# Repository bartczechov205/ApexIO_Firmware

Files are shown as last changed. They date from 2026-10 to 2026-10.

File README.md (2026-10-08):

ApexIO - 23.09.2026

O projekcie

ApexIO to projekt przenośnego urządzenia do telemetrii pojazdu, pomiaru przyspieszenia i czasów okrążeń. Inspiracją były rozwiązania RaceBox i Racelogic, a celem było połączenie podobnych funkcji we własnym urządzeniu z ekranem i fizycznymi przyciskami. Projekt obejmuje oprogramowanie, własną płytkę PCB zaprojektowaną w KiCad oraz obudowę przygotowaną w Fusion 360.

Podstawą urządzenia jest ESP32-S3-WROOM. Dane o pozycji, prędkości i czasie dostarcza odbiornik GNSS NEO-F10N pracujący z częstotliwością 10 Hz, natomiast czujnik BNO085 mierzy przyspieszenie, prędkość kątową i pole magnetyczne. Wyniki są prezentowane na ekranie TFT o przekątnej 2,4 cala.

Oprogramowanie powstało w C++ z wykorzystaniem Arduino, PlatformIO i FreeRTOS. Sześć zadań rozdzielonych pomiędzy dwa rdzenie procesora odpowiada za odczyt czujników, przetwarzanie danych, obsługę przycisków i ekranu oraz zapis na kartę microSD. Zadania wymieniają dane przez kolejki, a dostęp do wspólnych zasobów jest zabezpieczony mutexami.

Do łączenia pomiarów GNSS i IMU wykorzystano bibliotekę z implementacją rozszerzonego filtra Kalmana (EKF). Dane z IMU pozwalają śledzić zmiany ruchu między odczytami GNSS, a pomiary satelitarne korygują narastające błędy oszacowania pozycji i prędkości. GeoLib przelicza współrzędne geograficzne na lokalny układ kartezjański, umożliwiając wykonywanie obliczeń odległości w metrach.

Funkcje

Live Telemetry

Tryb wyświetla aktualną prędkość, przeciążenia w osiach pojazdu, przebyty dystans, przybliżoną wysokość i kierunek ruchu. Prędkość jest wyznaczana na podstawie danych z filtra EKF i dodatkowo wygładzana filtrem medianowym. Zastosowano również ograniczenie wahań wskazania prędkości podczas postoju.

Drag Mode

Tryb mierzy czas przyspieszenia od 0 do 100 km/h oraz czas pokonania 60 stóp, 100 m, 200 m i 400 m. Wyświetla także prędkość maksymalną i aktualne przeciążenie. Po uzyskaniu gotowości pomiar rozpoczyna się automatycznie po wykryciu ruszenia, a po przejechaniu 400 m możliwy jest również pomiar drogi hamowania.

Lap Timer

Tryb mierzy czasy kolejnych okrążeń oraz pokazuje poprzedni i najlepszy wynik. Podczas okrążenia zapoznawczego tworzy wirtualne bramki, których kolejność przekraczania służy do sprawdzania poprawności kolejnych przejazdów. Funkcja live delta pokazuje bieżący zysk lub stratę czasu względem najlepszego prawidłowego okrążenia. Dane sesji są zapisywane na karcie microSD w formacie .vbo do późniejszej analizy w Circuit Tools 3.

Settings

Ustawienia pozwalają sprawdzić ustawienie urządzenia w osiach X i Y oraz wybrać przesunięcie czasu względem UTC. Można również zmieniać szerokość linii startu i mety oraz wirtualnych bramek. Dodatkowo dostępna jest regulacja zakresu paska pokazującego różnicę czasu okrążenia.

Wykorzystane biblioteki

- TFT_eSPI – obsługuje wyświetlacz TFT. Służy do rysowania ekranów, tekstu, grafik i wskaźników oraz wyświetlania wyników pomiarów.

- SparkFun u-blox GNSS v3 – odpowiada za komunikację z modułem GPS/GNSS. Umożliwia konfigurację odbiornika oraz odczyt pozycji, prędkości, czasu i liczby widocznych satelitów.

- SparkFun BNO08x Cortex Based IMU – obsługuje czujnik IMU. Dostarcza odczyty z akcelerometru, żyroskopu i magnetometru wykorzystywane do obliczania ruchu i orientacji urządzenia.

- Bolder Flight Systems Eigen – umożliwia wykonywanie obliczeń na macierzach i wektorach. W projekcie jest wykorzystywana w implementacji rozszerzonego filtra Kalmana, który łączy dane z czujników.

- SdFat – odpowiada za obsługę karty SD i plików. Umożliwia tworzenie plików z danymi przejazdu oraz zapisywanie kolejnych próbek telemetrii.

- Adafruit INA219 – obsługuje układ pomiaru napięcia i prądu. W projekcie służy do odczytu napięcia wykorzystywanego przez wskaźnik baterii.

- GeoLib - zawiera obliczenia związane ze współrzędnymi geograficznymi. Ułatwia przeliczanie pozycji na lokalny układ współrzędnych wykorzystywany w pomiarach przejazdu. 

- Adafruit BusIO – zapewnia funkcje komunikacji przez magistrale I²C i SPI. Jest biblioteką pomocniczą wykorzystywaną przez sterowniki Adafruit, między innymi INA219.

- Adafruit GFX Library – zawiera podstawowe funkcje rysowania tekstu i kształtów. Jest dołączona w zestawie bibliotek Adafruit; za interfejs wyświetlacza w ApexIO odpowiada TFT_eSPI.

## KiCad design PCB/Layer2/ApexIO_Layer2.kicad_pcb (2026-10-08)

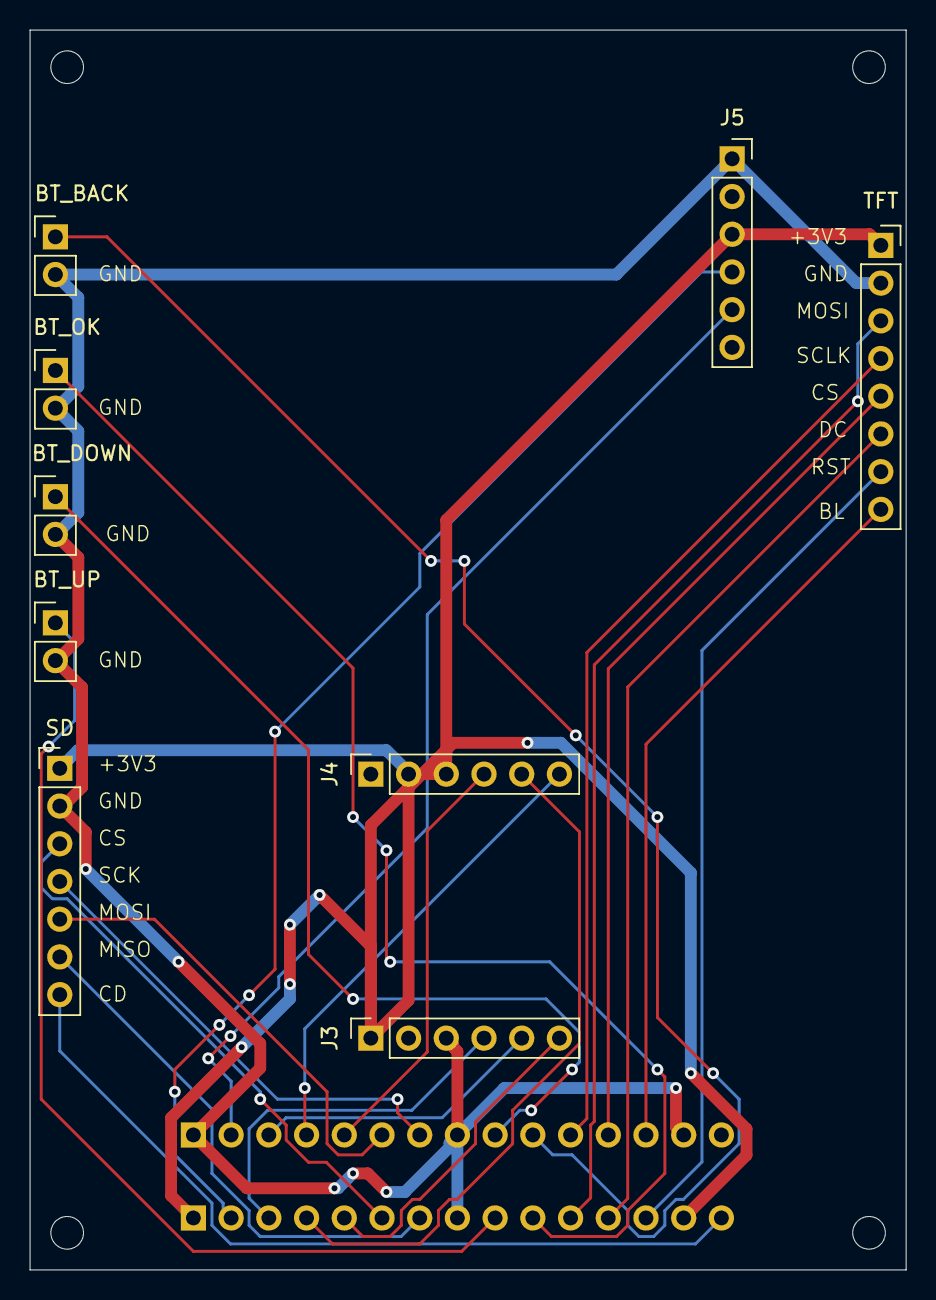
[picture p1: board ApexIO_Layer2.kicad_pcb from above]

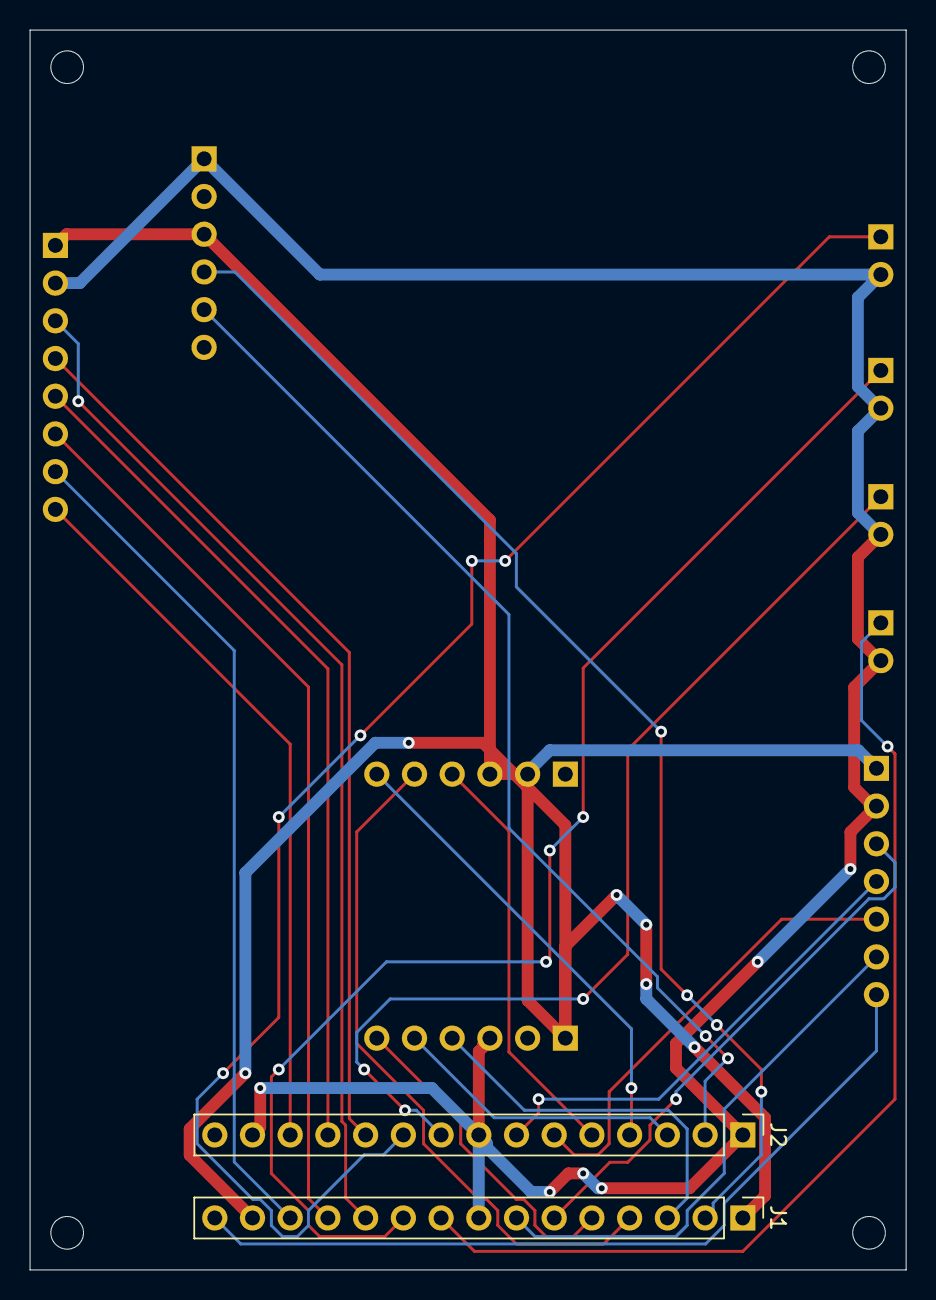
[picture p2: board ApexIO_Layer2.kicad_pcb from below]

Board: 2 copper layers, 59.0 x 83.5 mm, 11 parts (2 on the bottom side), 25 nets.

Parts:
BT_BACK: BUTTON_BACK; PinHeader_1x02_P2.54mm_Vertical
BT_DOWN: BUTTON_OK; PinHeader_1x02_P2.54mm_Vertical
BT_OK: BUTTON_DOWN; PinHeader_1x02_P2.54mm_Vertical
BT_UP: BUTTON_UP; PinHeader_1x02_P2.54mm_Vertical
J1: STACK_A; PinHeader_1x15_P2.54mm_Vertical
J2: STACK_B; PinHeader_1x15_P2.54mm_Vertical
J3: IMU_R1; PinSocket_1x06_P2.54mm_Vertical
J4: IMU_R2; PinSocket_1x06_P2.54mm_Vertical
J5: GPS_GNSS; PinSocket_1x06_P2.54mm_Vertical
SD: SD_WIRES; PinHeader_1x07_P2.54mm_Vertical
TFT: STACK_3; PinSocket_1x08_P2.54mm_Vertical

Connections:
/+3V3: J1.1, J1.14, J3.1, J4.2, J4.3, J5.3, SD.1, TFT.1
/BTN_BACK: BT_BACK.1, J2.10
/BTN_DOWN: BT_OK.1, J2.9
/BTN_OK: BT_DOWN.1, J1.10
/BTN_UP: BT_UP.1, J1.9
/GND: BT_BACK.2, BT_DOWN.2, BT_OK.2, BT_UP.2, J1.8, J2.1, J2.8, J2.14, J3.3, J5.1, SD.2, TFT.2
/GPS_RX: J2.2, J5.5
/GPS_TX: J1.2, J5.4
/IMU_CS: J2.4, J4.6
/IMU_INT: J1.5, J3.6
/IMU_MISO: J2.3, J3.5
/IMU_MOSI: J1.4, J4.5
/IMU_RST: J2.5, J4.4
/IMU_SCK: J1.3, J3.4
/SD_CD: J1.15, SD.7
/SD_CS: J1.6, SD.3
/SD_MISO: J1.7, SD.6
/SD_MOSI: J2.6, SD.5
/SD_SCK: J2.7, SD.4
/TFT_BL_CTRL: J2.13, TFT.8
/TFT_CS: J2.12, TFT.5
/TFT_DC: J1.12, TFT.6
/TFT_MOSI: J1.11, TFT.3
/TFT_RST: J1.13, TFT.7
/TFT_SCLK: J2.11, TFT.4

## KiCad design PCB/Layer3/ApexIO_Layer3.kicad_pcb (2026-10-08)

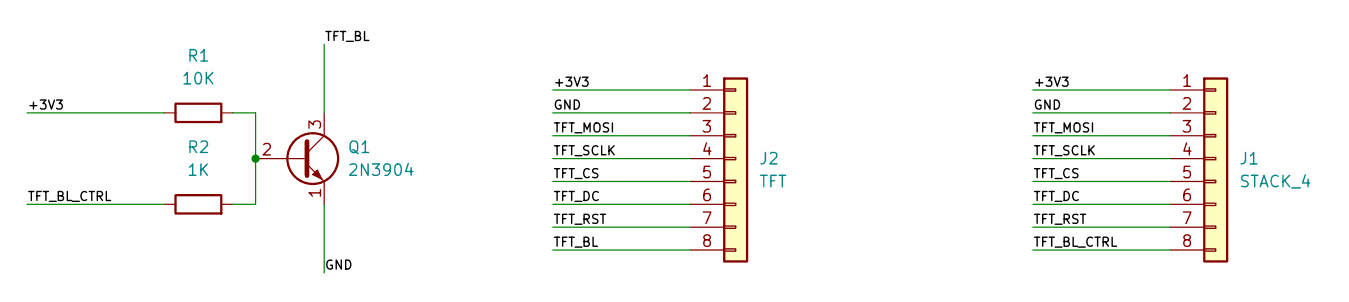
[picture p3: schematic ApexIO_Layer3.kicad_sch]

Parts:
J1: STACK_4; PinHeader_1x08_P2.54mm_Vertical
J2: TFT; PinHeader_1x08_P2.54mm_Vertical
Q1: 2N3904; TO-92_Inline
R1: 10K; R_Axial_DIN0207_L6.3mm_D2.5mm_P7.62mm_Horizontal
R2: 1K; R_Axial_DIN0207_L6.3mm_D2.5mm_P7.62mm_Horizontal

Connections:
/+3V3: J1.1, J2.1, R1.1
/GND: J1.2, J2.2, Q1.1 (E)
/TFT_BL: J2.8, Q1.3 (C)
/TFT_BL_CTRL: J1.8, R2.1
/TFT_CS: J1.5, J2.5
/TFT_DC: J1.6, J2.6
/TFT_MOSI: J1.3, J2.3
/TFT_RST: J1.7, J2.7
/TFT_SCLK: J1.4, J2.4
unnamed: Q1.2 (B), R1.2, R2.2

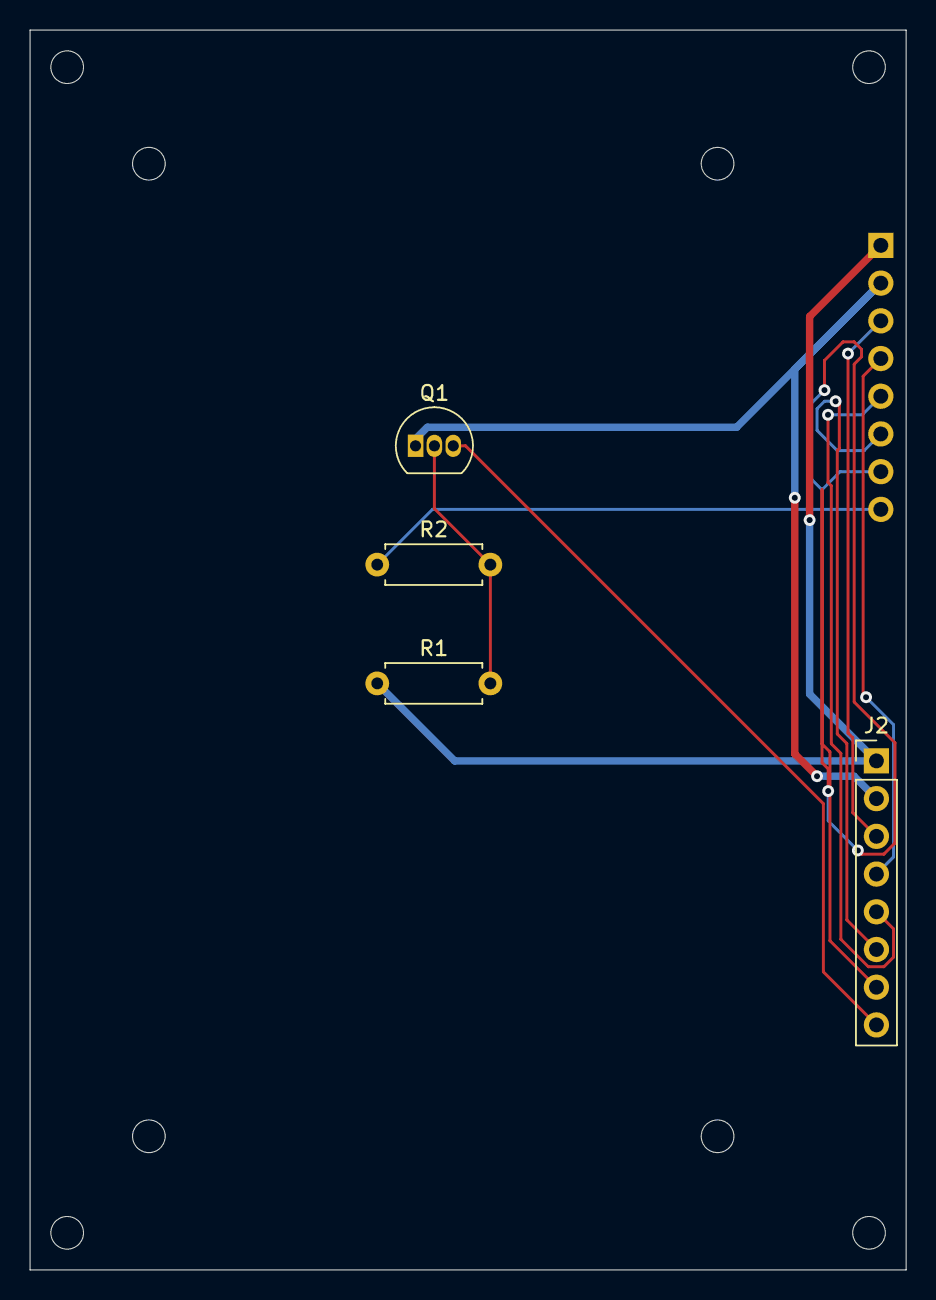
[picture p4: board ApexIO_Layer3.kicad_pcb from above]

Board: 2 copper layers, 59.0 x 83.5 mm, 5 parts (1 on the bottom side), 10 nets.

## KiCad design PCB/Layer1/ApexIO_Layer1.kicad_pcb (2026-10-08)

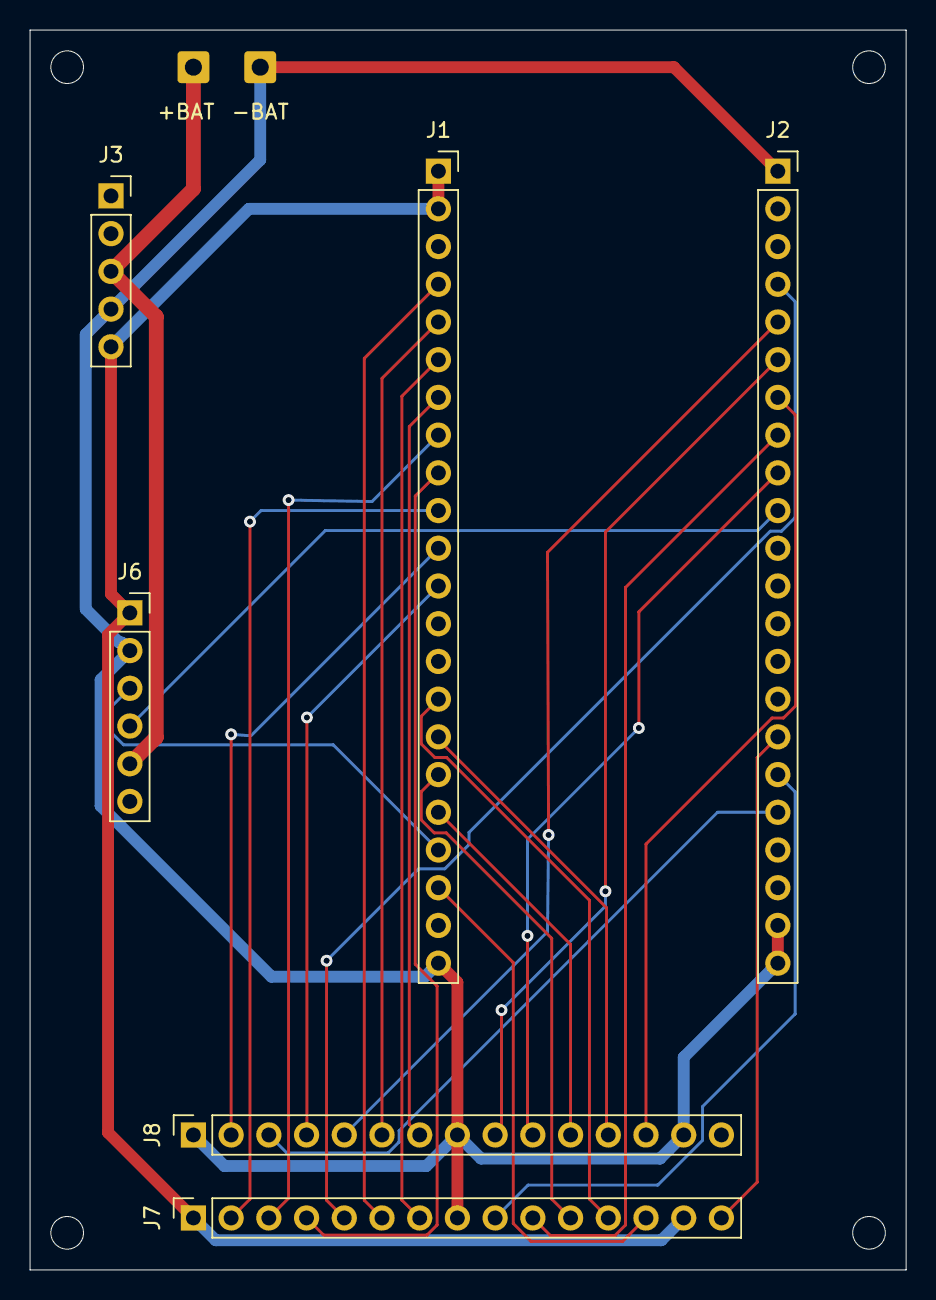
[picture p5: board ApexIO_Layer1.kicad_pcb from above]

Board: 2 copper layers, 59.0 x 83.5 mm, 8 parts (0 on the bottom side), 28 nets.

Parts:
+BAT: BAT_PLUS; SolderWire-0.5sqmm_1x01_D0.9mm_OD2.1mm
-BAT: BAT_MINUS; SolderWire-0.5sqmm_1x01_D0.9mm_OD2.1mm
J1: ESP32_P1; PinSocket_1x22_P2.54mm_Vertical
J2: ESP32_P2; PinSocket_1x22_P2.54mm_Vertical
J3: Pololu D24V22F3; PinSocket_1x05_P2.54mm_Vertical
J6: INA219_Adafruit; PinSocket_1x06_P2.54mm_Vertical
J7: STACK_A; PinSocket_1x15_P2.54mm_Vertical
J8: STACK_B; PinSocket_1x15_P2.54mm_Vertical

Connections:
/+3V3: J1.1, J1.2, J3.5, J6.1, J7.1, J7.14
/BTN_BACK: J2.9, J8.10
/BTN_DOWN: J2.6, J8.9
/BTN_OK: J2.8, J7.10
/BTN_UP: J2.17, J7.9
/GND: -BAT.1 (Pin_1_1), J1.22, J2.1, J2.21, J2.22, J3.4, J6.2, J7.8, J8.1, J8.8, J8.14
/GPS_RX: J1.11, J8.2
/GPS_TX: J1.10, J7.2
/I2C_SCL: J1.19, J6.3
/I2C_SDA: J2.10, J6.4
/IMU_CS: J1.12, J8.4
/IMU_INT: J2.4, J7.5
/IMU_MISO: J2.18, J8.3
/IMU_MOSI: J1.9, J7.4
/IMU_RST: J2.5, J8.5
/IMU_SCK: J1.8, J7.3
/SD_CD: J2.16, J7.15
/SD_CS: J1.4, J7.6
/SD_MISO: J1.6, J7.7
/SD_MOSI: J1.5, J8.6
/SD_SCK: J1.7, J8.7
/TFT_BL_CTRL: J2.7, J8.13
/TFT_CS: J1.16, J8.12
/TFT_DC: J1.15, J7.12
/TFT_MOSI: J1.17, J7.11
/TFT_RST: J1.20, J7.13
/TFT_SCLK: J1.18, J8.11
/VBAT: +BAT.1 (Pin_1_1), J3.3, J6.5

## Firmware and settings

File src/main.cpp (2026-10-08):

#include <Arduino.h>
#include "Macro.h"
#include "SharedBegin.h"
#include "ekfNavINS.h"
#include <TFT_eSPI.h>
#include "AppStateManager.h"
#include "TelemetryEngine.h"
#include "TFTManager.h"
#include "SystemDataUpdater.h"
#include "AppResources.h"
#include "SDManager.h"

SharedBegin sharedBegin;
IMUManager imuManager;
GPSManager gpsManager;
ekfNavINS ekfNavIns;
AppStateManager appStateManager;
TelemetryEngine telemetryEngine;
TFTManager tftManager;
SDManager sdManager;

SystemDataUpdater systemDataUpdater;
AppResources resources;

void IRAM_ATTR imuInt()
{
    BaseType_t xHigherPriorityTaskWoken = pdFALSE;

    xSemaphoreGiveFromISR(resources.imuSemaphore, &xHigherPriorityTaskWoken);

    portYIELD_FROM_ISR(xHigherPriorityTaskWoken);
}

void vTaskIMU(void *pvParameters)
{
    for (;;)
    {
        imuManager.processImuData(resources,ekfNavIns,systemDataUpdater);
        vTaskDelay(pdMS_TO_TICKS(1));
    }
}

void vTaskGPS(void *pvParameters)
{
    for (;;)
    {
        gpsManager.processGpsData(resources, ekfNavIns);

        vTaskDelay(pdMS_TO_TICKS(5));
    }
}

void vTaskAppState(void *pvParametrs)
{
    bool validFix = false;
    bool canContinue = false;

    for (;;)
    {
        if (xSemaphoreTake(resources.systemStateMutex, portMAX_DELAY) == pdTRUE)
        {
            validFix = resources.validFix;

            if (resources.validFix && resources.systemReady)
            {
                canContinue = true;
            }
            else
            {
                canContinue = false;
            }
            xSemaphoreGive(resources.systemStateMutex);
        }

        appStateManager.updateState(validFix, canContinue);
        vTaskDelay(pdMS_TO_TICKS(5));
    }
}

void vTaskTelemetryEngine(void *pvParameters)
{
    for (;;)
    {
        if (xSemaphoreTake(resources.systemStateMutex, portMAX_DELAY) == pdTRUE)
        {
            telemetryEngine.updateTelemetryEngine(resources.systemData);
            xSemaphoreGive(resources.systemStateMutex);
        }

        telemetryEngine.processDataForState(appStateManager);

        vTaskDelay(pdMS_TO_TICKS(10));
    }
}

void vTaskTFT(void *pvParametrs)
{
    DisplayResources displayResources;

    tftManager.drawSplashScreen();

    displayResources.startTime = millis();

    for (;;)
    {
        tftManager.updateDisplay(resources,appStateManager,displayResources);

        vTaskDelay(pdMS_TO_TICKS(5));
    }
}

void vTaskSD(void *pvParameters)
{
    SDData sdReceived;

    bool isFileOpen = false;

    if (!sdManager.begin())
    {
        vTaskDelete(NULL);
    }

    for (;;)
    {
        if (xQueueReceive(resources.lapTimerSDQueue, &sdReceived, portMAX_DELAY) == pdTRUE)
        {
            sdManager.processSdRecord(sdReceived, isFileOpen);
        }
    }
}

void setup()
{
    digitalWrite(TFT_BL, HIGH);
    pinMode(TFT_BL, OUTPUT);

    pinMode(SD_DETECT_PIN, INPUT_PULLUP);

    Serial.begin(115200);
    delay(200);

    resources.imuSemaphore = xSemaphoreCreateBinary();
    resources.systemStateMutex = xSemaphoreCreateMutex();
    resources.serialMonitorMutex = xSemaphoreCreateMutex();

    resources.imuQueue = xQueueCreate(10, sizeof(imuData));
    resources.magQueue = xQueueCreate(10, sizeof(magData));
    resources.gpsPositionQueue = xQueueCreate(10, sizeof(gpsPosData));
    resources.gpsVelocityQueue = xQueueCreate(10, sizeof(gpsVelData));
    resources.gpsExtraQueue = xQueueCreate(10, sizeof(gpsExtraData));
    resources.lapTimerSDQueue = xQueueCreate(128, sizeof(SDData));

    resources.axisCalibQueue = xQueueCreate(1, sizeof(AxisCalibData));
    resources.liveTelemetryQueue = xQueueCreate(1, sizeof(LiveTeleData));
    resources.dragModeQueue = xQueueCreate(1, sizeof(DragModeData));
    resources.lapTimerQueue = xQueueCreate(1, sizeof(LapTimerData));

    if (!sharedBegin.begin(resources))
    {
        return;
    }

    attachInterrupt(digitalPinToInterrupt(IMU_INT), imuInt, FALLING);

    xTaskCreatePinnedToCore(vTaskIMU, "vTaskIMU", 16384, NULL, 5, NULL, 0);
    xTaskCreatePinnedToCore(vTaskGPS, "vTaskGPS", 16384, NULL, 4, NULL, 0);
    xTaskCreatePinnedToCore(vTaskAppState, "vTaskAppState", 4096, NULL, 2, NULL, 1);
    xTaskCreatePinnedToCore(vTaskTFT, "vTaskTFT", 8192, NULL, 2, NULL, 1);
    xTaskCreatePinnedToCore(vTaskTelemetryEngine, "vTaskTelemetryEngine", 8192, NULL, 3, NULL, 1);
    xTaskCreatePinnedToCore(vTaskSD, "vTaskSD", 8192, NULL, 1, NULL, 1);

    delay(500);
}

void loop() {}

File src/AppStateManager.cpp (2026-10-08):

#include "AppStateManager.h"
#include "AppResources.h"

extern AppResources resources;

void AppStateManager::begin()
{
    currentState = State_Splash;
    okPressed = false;
    wasPressed = false;

    Serial.println("Splash screen, press OK");
}

void AppStateManager::updateState(bool validFix, bool canContinue)
{
    bool upState = digitalRead(btn_up.pin);
    bool downState = digitalRead(btn_down.pin);
    bool okState = digitalRead(btn_ok.pin);
    bool backState = digitalRead(btn_back.pin);

    bool upClick = false;
    bool downClick = false;
    bool okClick = false;
    bool backClick = false;

    if (upState == LOW && btn_up.lastPinState == HIGH)
    {
        if (millis() - btn_up.lastButtonPressTime > debounceDelay)
        {
            upClick = true;
            btn_up.lastButtonPressTime = millis();
        }
    }

    if (downState == LOW && btn_down.lastPinState == HIGH)
    {
        if (millis() - btn_down.lastButtonPressTime > debounceDelay)
        {
            downClick = true;
            btn_down.lastButtonPressTime = millis();
        }
    }

    if (okState == LOW && btn_ok.lastPinState == HIGH)
    {
        if (millis() - btn_ok.lastButtonPressTime > debounceDelay)
        {
            okClick = true;
            btn_ok.lastButtonPressTime = millis();
        }
    }

    if (backState == LOW && btn_back.lastPinState == HIGH)
    {
        if (millis() - btn_back.lastButtonPressTime > debounceDelay)
        {
            backClick = true;
            btn_back.lastButtonPressTime = millis();
        }
    }

    switch (currentState)
    {
    case State_Splash:
        if (validFix && canContinue && okClick)
        {
            currentState = State_LiveTeleSel;
        }
        break;

    case State_LiveTeleSel:
        if (okClick)
        {
            currentState = State_LiveTele;
        }
        else if (downClick)
        {
            currentState = State_DragModeSel;
        }
        else if (upClick)
        {
            currentState = State_SettingsSel;
        }
        break;

    case State_DragModeSel:
        if (okClick)
        {
            currentState = State_DragMode;
        }
        else if (downClick)
        {
            currentState = State_LapTimerSel;
        }
        else if (upClick)
        {
            currentState = State_LiveTeleSel;
        }
        break;

    case State_LapTimerSel:
        if (okClick)
        {
            currentState = State_LapTimer;
        }
        else if (downClick)
        {
            currentState = State_SettingsSel;
        }
        else if (upClick)
        {
            currentState = State_DragModeSel;
        }
        break;

    case State_SettingsSel:
        if (okClick)
        {
            currentState = State_Settings_Axis_CalibSel;
        }
        else if (downClick)
        {
            currentState = State_LiveTeleSel;
        }
        else if (upClick)
        {
            currentState = State_LapTimerSel;
        }
        break;

    case State_LiveTele:
        if (backClick)
        {
            currentState = State_LiveTeleSel;
        }
        break;

    case State_DragMode:
        if (backClick)
        {
            currentState = State_DragModeSel;
        }
        else if (okClick)
        {
            okPressed = true;
        }
        break;

    case State_LapTimer:
        if (backClick)
        {
            currentState = State_LapTimerSel;
        }
        else if (okClick)
        {
            okPressed = true;
        }
        break;

    case State_Settings_Axis_CalibSel:
        if (backClick)
        {
            currentState = State_SettingsSel;
        }
        else if (okClick)
        {
            currentState = State_Settings_Axis_Calib;
        }
        else if (downClick)
        {
            currentState = State_Settings_UTC_OFFSETSel;
        }
        else if (upClick)
        {
            currentState = State_Settings_ABOUTSel;
        }
        break;

    case State_Settings_UTC_OFFSETSel:
        if (backClick)
        {
            currentState = State_SettingsSel;
        }
        else if (okClick)
        {
            currentState = State_Settings_UTC_OFFSET;
        }
        else if (downClick)
        {
            currentState = State_Settings_GATE_SETUPSel;
        }
        else if (upClick)
        {
            currentState = State_Settings_Axis_CalibSel;
        }
        break;

    case State_Settings_GATE_SETUPSel:
        if (backClick)
        {
            currentState = State_SettingsSel;
        }
        else if (okClick)
        {
            currentState = State_StartLineWidthSel;
        }
        else if (downClick)
        {
            currentState = State_Settings_ABOUTSel;
        }
        else if (upClick)
        {
            currentState = State_Settings_UTC_OFFSETSel;
        }
        break;

    case State_Settings_ABOUTSel:
        if (backClick)
        {
            currentState = State_SettingsSel;
        }
        else if (okClick)
        {
            currentState = State_Settings_ABOUT;
        }
        else if (downClick)
        {
            currentState = State_Settings_Axis_CalibSel;
        }
        else if (upClick)
        {
            currentState = State_Settings_GATE_SETUPSel;
        }
        break;

    case State_Settings_Axis_Calib:
        if (backClick)
        {
            currentState = State_Settings_Axis_CalibSel;
        }
        break;

    case State_Settings_UTC_OFFSET:
        if (backClick)
        {
            currentState = State_Settings_UTC_OFFSETSel;
        }
        else if (upClick)
        {
            if (resources.utcOffset < 12)
            {
                resources.utcOffset++;
            }
        }
        else if (downClick)
        {
            if (resources.utcOffset > -12)
            {
                resources.utcOffset--;
            }
        }
        break;

    case State_StartLineWidthSel:
        if (backClick)
        {
            currentState = State_Settings_GATE_SETUPSel;
        }
        else if (okClick)
        {
            currentState = State_StartLineWidth;
        }
        else if (downClick)
        {
            currentState = State_GateWidthSel;
        }
        else if (upClick)
        {
            currentState = State_DeltaMaxSel;
        }
        break;

    case State_GateWidthSel:
        if (backClick)
        {
            currentState = State_Settings_GATE_SETUPSel;
        }
        else if (okClick)
        {
            currentState = State_GateWidth;
        }
        else if (downClick)
        {
            currentState = State_DeltaMaxSel;
        }
        else if (upClick)
        {
            currentState = State_StartLineWidthSel;
        }
        break;
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
